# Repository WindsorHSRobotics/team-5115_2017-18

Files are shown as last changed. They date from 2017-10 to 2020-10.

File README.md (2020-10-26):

# Team-5115 (2017-18)
## Message from the repository creator, the Great, Anthony Romero: "This is the team 5115 2017 repository...don't break it!"

This repository is the result of the hard work of one of the greatest WHS robotics teams.  The members of this team were Anthony Romero, Dominic Scolari, Gavin Parrot and Liam McFadden.  Were it not for the failure to test the "claw systen" more thoroughly towards the end, they could have gone all the way (Let that be a lesson to all - fail to test at your own peril!).  Their repository includes an innovative omni wheel drive system using trigonometry which has resulted in a smoother, more responsive drive control all around.  Their innovative part designs should serve as an inspiration to all who view them.  Great work gentlemen, you will be immortalized here on GitHub.



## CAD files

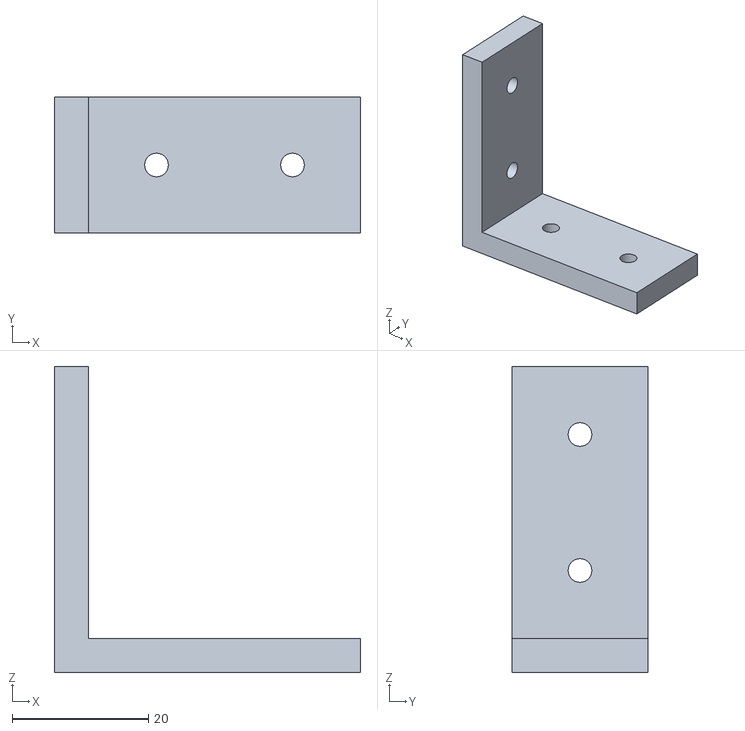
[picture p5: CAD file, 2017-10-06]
prints/8020 brackets/stl files/90 degree corner bracket.stl
45.0 x 20.0 x 45.0

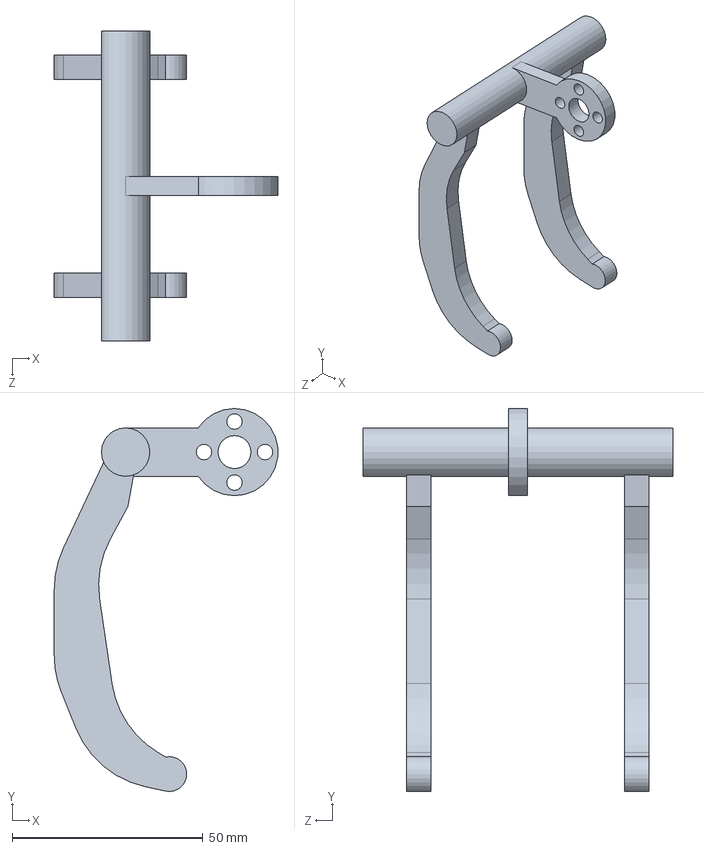
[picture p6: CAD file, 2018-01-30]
prints/adapters/sketchup of fusion files/clawmk2.SLDPRT
58.6 x 100.4 x 81.3 mm

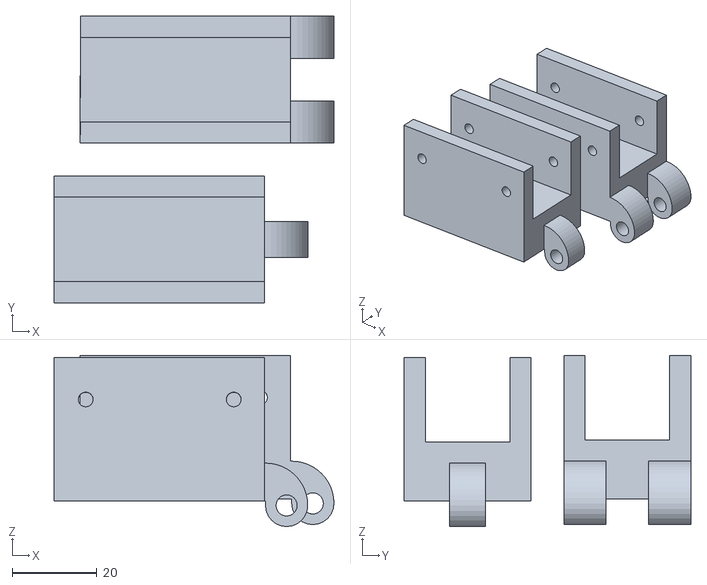
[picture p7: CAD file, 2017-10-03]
prints/connectors/hinges/sti files/Hinge a gavin1.stl
66.2 x 67.8 x 40.5

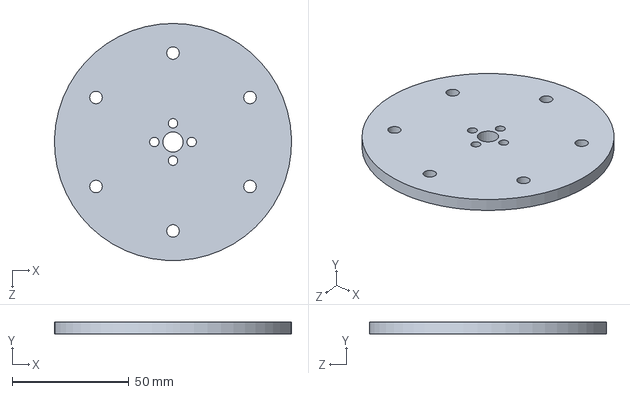
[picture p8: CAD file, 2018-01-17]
prints/gears/pinion roller mk1.SLDPRT
101.6 x 5.08 x 101.6 mm

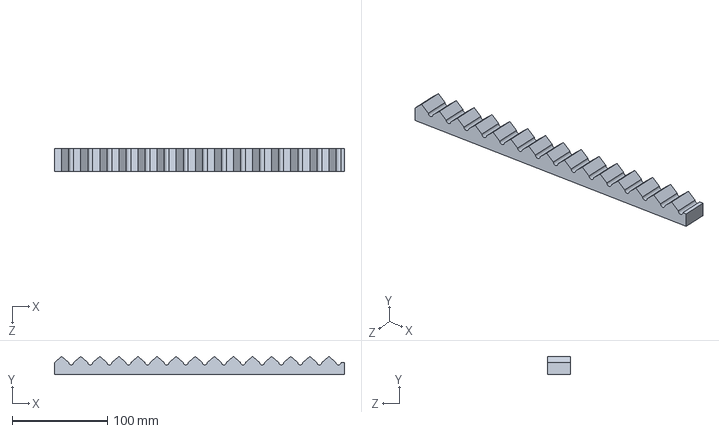
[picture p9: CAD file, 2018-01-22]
prints/gears/soldworks or fussion files/pinion rack mk2.SLDPRT
304.8 x 19.0 x 24.1 mm

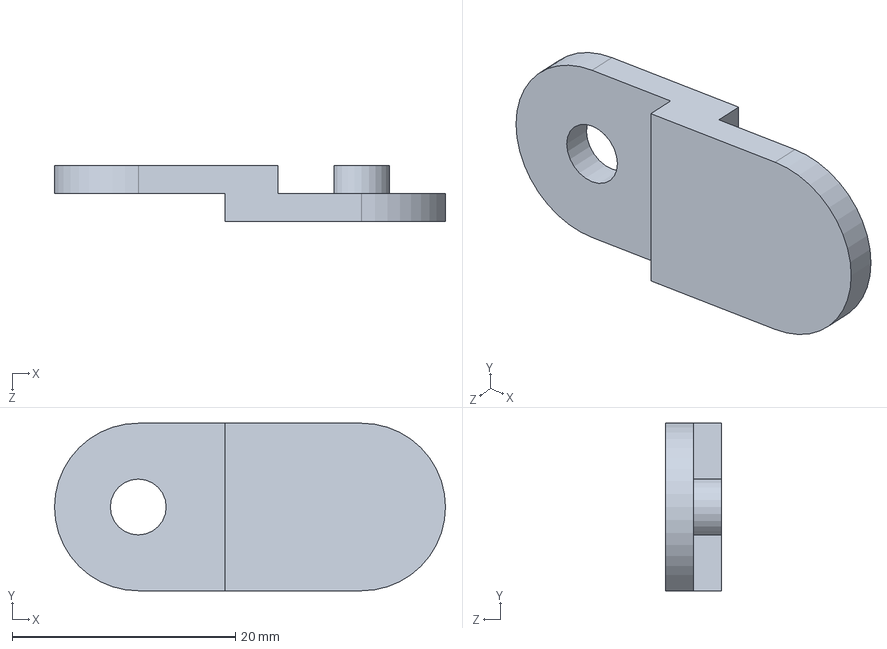
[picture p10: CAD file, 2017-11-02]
prints/wire protect track/leftmk1.SLDPRT
35.0 x 15.0 x 5.00 mm

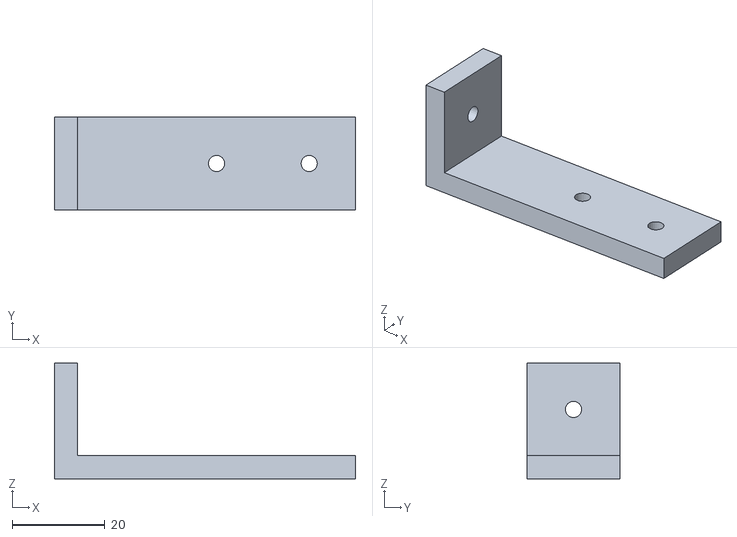
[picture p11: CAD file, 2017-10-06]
prints/8020 brackets/stl files/90 degree single anchor.stl
65.0 x 20.0 x 25.0

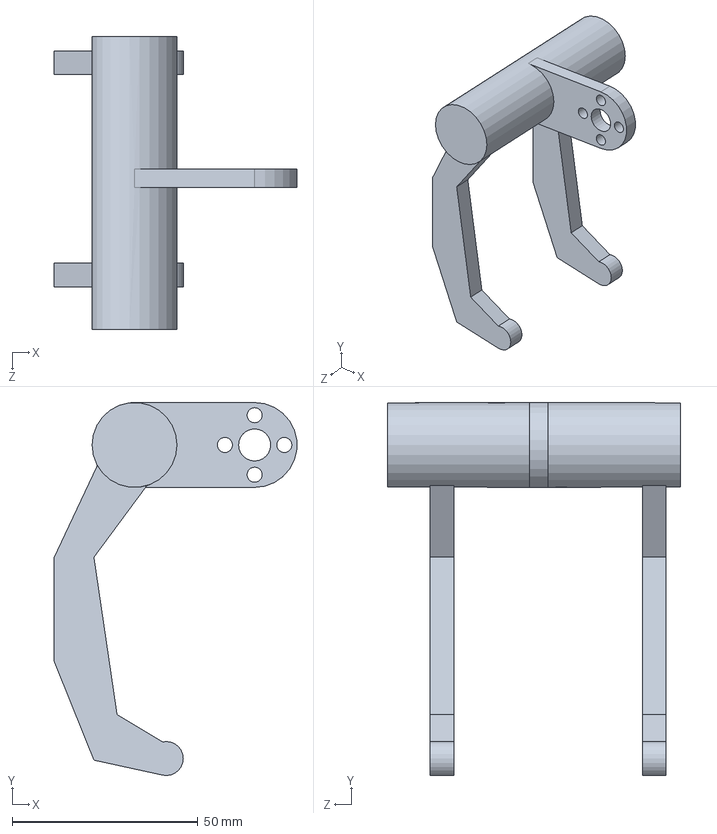
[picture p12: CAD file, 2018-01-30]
prints/adapters/sketchup of fusion files/clawmk3.SLDPRT
65.3 x 100.4 x 78.7 mm

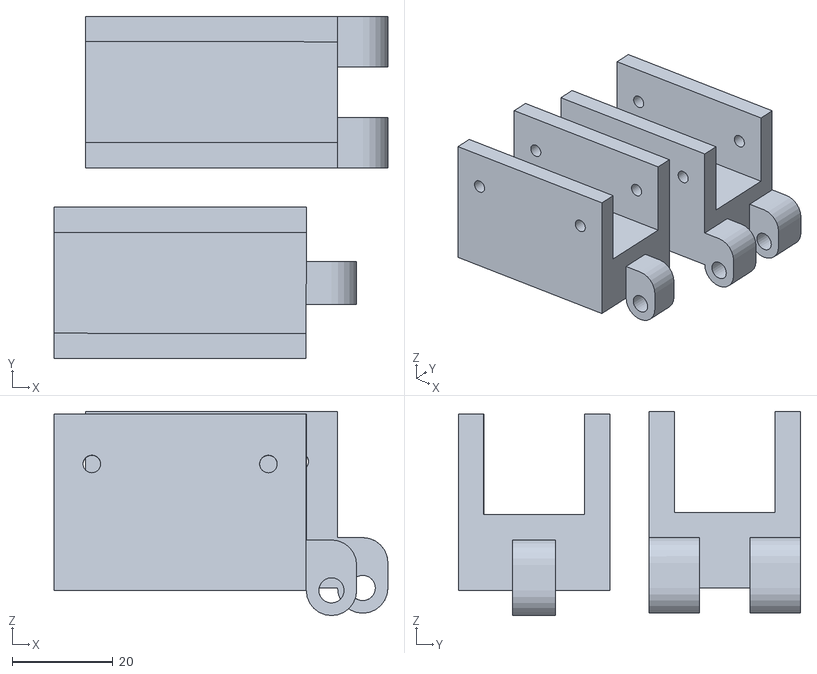
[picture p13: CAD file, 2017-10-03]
prints/connectors/hinges/sti files/hinge a gavin.stl
66.2 x 67.8 x 40.5

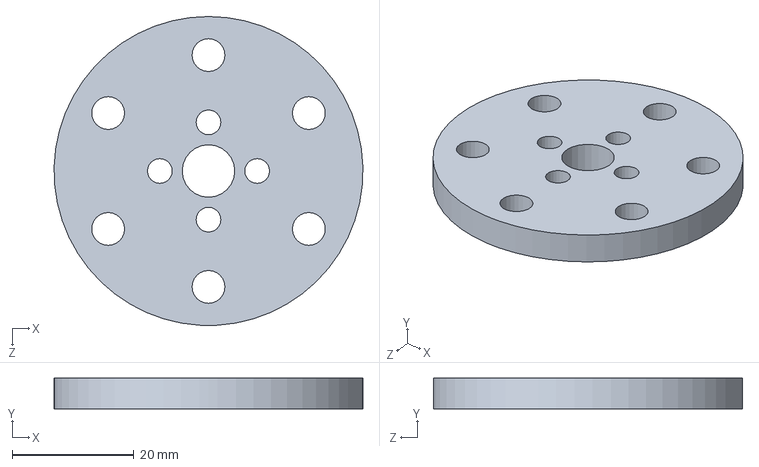
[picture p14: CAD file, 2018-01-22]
prints/gears/soldworks or fussion files/pinion roller mk2.SLDPRT
50.8 x 5.08 x 50.8 mm

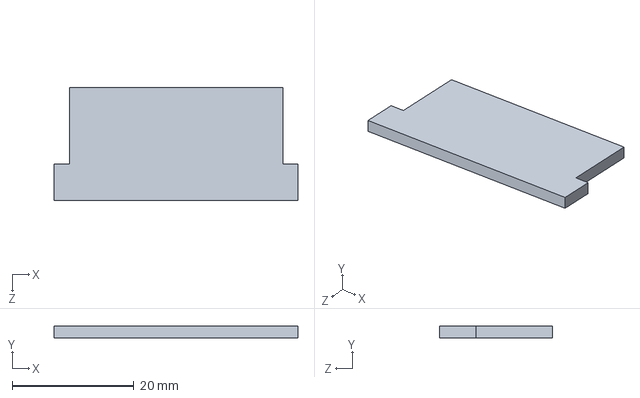
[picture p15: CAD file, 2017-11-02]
prints/wire protect track/tope wire protect track.SLDPRT
40.0 x 2.00 x 18.5 mm

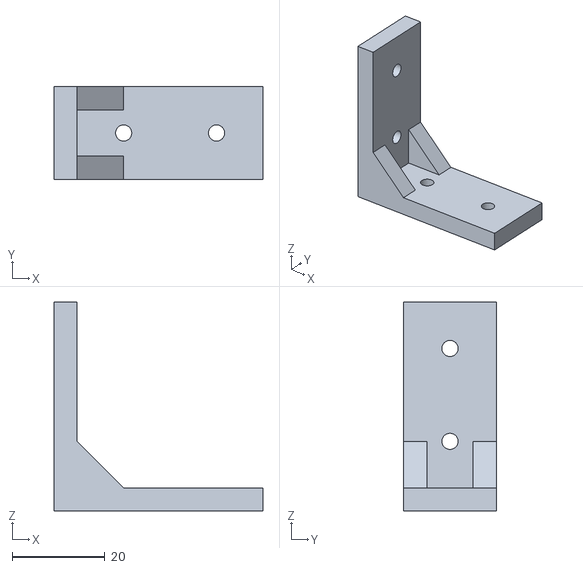
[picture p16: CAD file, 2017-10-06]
prints/8020 brackets/stl files/90 degree corner bracket with angle support.stl
45.0 x 20.0 x 45.0

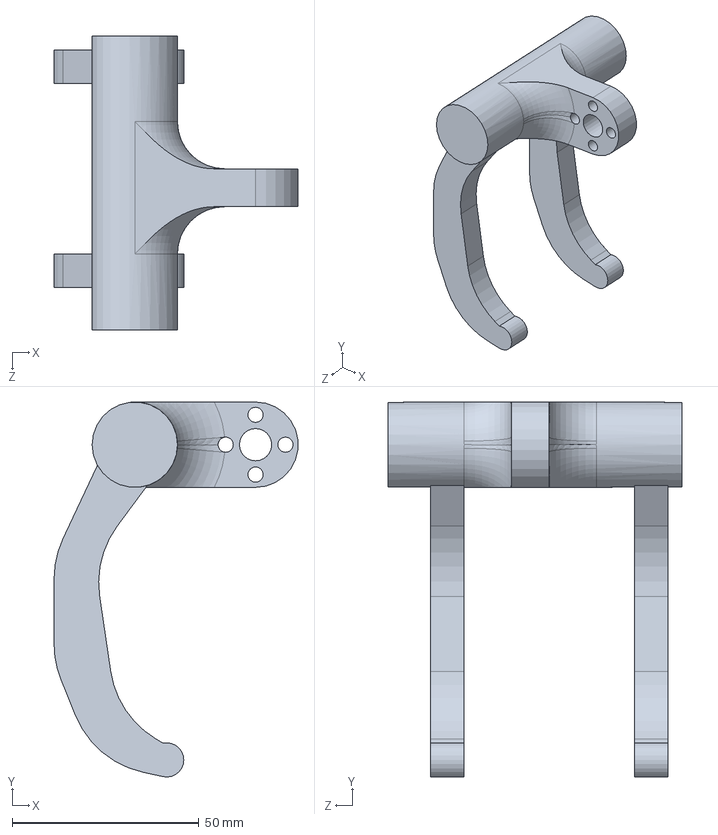
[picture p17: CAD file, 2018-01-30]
prints/adapters/sketchup of fusion files/clawmk4.SLDPRT
65.3 x 100.4 x 78.7 mm

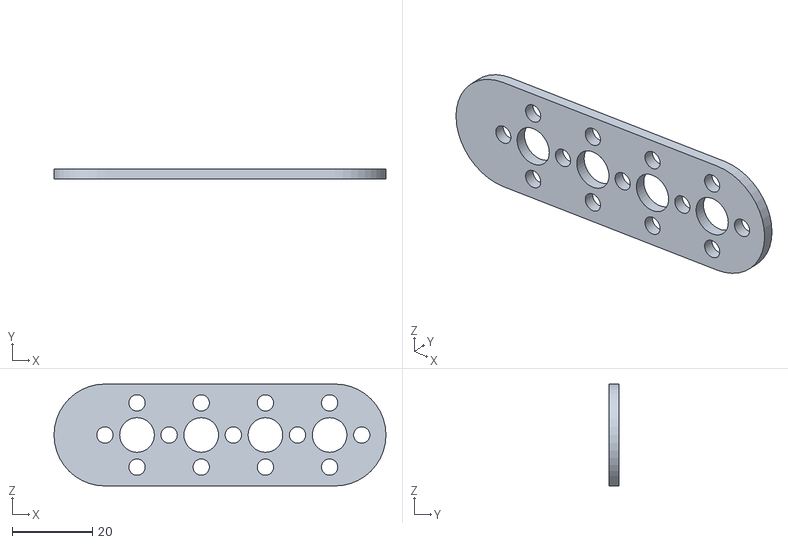
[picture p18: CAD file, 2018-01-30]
prints/adapters/stl files/phone mount platform.STL
82.8 x 2.54 x 25.4

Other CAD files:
prints/adapters/stl files/clawmk2.SLDPRT
prints/gears/stl files/pinion rack mk2.STL
prints/adapters/stl files/clawmk3.SLDPRT
prints/gears/stl files/pinion roller mk2.STL
prints/8020 brackets/sketchup or fusion files/90 degree 3 way corner bracket.skp
prints/8020 brackets/sketchup or fusion files/90 degree corner bracket with angle support.skp
prints/8020 brackets/sketchup or fusion files/90 degree corner bracket.skp
prints/8020 brackets/sketchup or fusion files/90 degree joining plane.skp
prints/8020 brackets/sketchup or fusion files/90 degree single anchor.skp
prints/8020 brackets/sketchup or fusion files/t joining plate.skp
prints/8020 brackets/stl files/90 degree 3 way corner bracket.stl
prints/8020 brackets/stl files/90 degree joining plane.stl
prints/8020 brackets/stl files/t joining plate.stl
prints/adapters/sketchup of fusion files/4in mechanum adapter.SLDPRT
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

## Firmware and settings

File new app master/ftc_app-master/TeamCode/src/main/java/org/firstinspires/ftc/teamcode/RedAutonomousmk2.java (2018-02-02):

package org.firstinspires.ftc.teamcode;
import com.qualcomm.robotcore.eventloop.opmode.Autonomous;
import com.qualcomm.robotcore.eventloop.opmode.Disabled;
import com.qualcomm.robotcore.eventloop.opmode.OpMode;
import com.qualcomm.robotcore.eventloop.opmode.TeleOp;
import com.qualcomm.robotcore.hardware.ColorSensor;
import com.qualcomm.robotcore.hardware.DcMotor;
import com.qualcomm.robotcore.hardware.DcMotorSimple;

import com.qualcomm.robotcore.hardware.Servo;
import com.qualcomm.robotcore.util.ElapsedTime;
import com.qualcomm.robotcore.util.Range;
import com.qualcomm.ftccommon.ClassManagerFactory;
import com.qualcomm.robotcore.hardware.CRServo;
import java.math.*;
import com.qualcomm.robotcore.eventloop.opmode.LinearOpMode;
import com.qualcomm.robotcore.hardware.DeviceInterfaceModule;
import com.qualcomm.robotcore.hardware.DigitalChannel;
import android.app.Activity;
import android.graphics.Color;
import android.view.View;

import org.firstinspires.ftc.robotcore.external.ClassFactory;
import org.firstinspires.ftc.robotcore.external.matrices.OpenGLMatrix;
import org.firstinspires.ftc.robotcore.external.navigation.RelicRecoveryVuMark;
import org.firstinspires.ftc.robotcore.external.navigation.VuforiaLocalizer;
import org.firstinspires.ftc.robotcore.external.navigation.VuforiaTrackable;
import org.firstinspires.ftc.robotcore.external.navigation.VuforiaTrackables;

/**
 * Created by romer on 2/2/2018.
 */
@Autonomous(name = "redautonomousmk2", group = "autonomous")
public class RedAutonomousmk2 extends LinearOpMode {
    public static final String TAG = "Vuforia VuMark Sample";
    OpenGLMatrix lastLocation = null;
    VuforiaLocalizer vuforia;


    private DcMotor F1 = null;
    private DcMotor F2 = null;
    private DcMotor R1 = null;
    private DcMotor R2 = null;
    //private DcMotor Winch = null;
    private CRServo claw_rotate = null;
    private DcMotor arm_rotate = null;
    private DcMotor extend = null;
    private DcMotor arm_rotate2;

    private Servo claw_front_left = null;
    private Servo claw_front_right = null;
    private Servo claw_rear_left = null;
    private Servo claw_rear_right = null;

    public ColorSensor color_sensor_front = null;
    @Override
    public void runOpMode(){
        //Initialize Vuforia
        int cameraMonitorViewId = hardwareMap.appContext.getResources().getIdentifier("cameraMonitorViewId", "id", hardwareMap.appContext.getPackageName());
        VuforiaLocalizer.Parameters parameters = new VuforiaLocalizer.Parameters(cameraMonitorViewId);
        parameters.vuforiaLicenseKey = "Aejo+Mn/////AAAAmYNCqjLr6Uddg42ubg+VizqJNbtrK1Kt0bA39uknxmHOwtAspXh3VmGQffi7LjZ4vshTH2jU+q0HDkzlWLa7mVdKrOxOhZS7SA4by5JBrGNlcOoIeE7xQjLZSIRVJb3mKWoijXBWAvi9E261Mm0eCtk45eLhoknnYRlFhJNqAJgHyIHZsaQ2OJYTpP0e4cMRCYpiYKUr0ceEA/sb/aulvf9tpvHMyO2cWXS4MtJLP6nEmjc4JX6F2vXtabQZuSi1cVLLqjf+395Z2pqkjYAMHRYg+s2+sd4y+3wglEKEI2ZeFajmP60WuIFBY5rb583ywQdJqjHgjl2yK4egY2I6Yr0KB2PElwduB383oTJR535A";
        parameters.cameraDirection = VuforiaLocalizer.CameraDirection.BACK;
        this.vuforia = ClassFactory.createVuforiaLocalizer(parameters);
        VuforiaTrackables relicTrackables = this.vuforia.loadTrackablesFromAsset("RelicVuMark");
        VuforiaTrackable relicTemplate = relicTrackables.get(0);
        relicTemplate.setName("relicVuMarkTemplate"); // can help in debugging; otherwise not necessary

        telemetry.addData(">", "Press Play to start");
        telemetry.update();

        relicTrackables.activate();

        telemetry.addData("Status", "Initialized");

        //Initialize hardware components
        F1 = hardwareMap.get(DcMotor.class, "F1");
        F2 = hardwareMap.get(DcMotor.class, "F2");
        R1 = hardwareMap.get(DcMotor.class, "R1");
        R2 = hardwareMap.get(DcMotor.class, "R2");
        arm_rotate2 = hardwareMap.get(DcMotor.class, "arm_rotate2");
        arm_rotate = hardwareMap.get(DcMotor.class,"arm_rotate");
        claw_rotate = hardwareMap.get(CRServo.class,"claw_rotate");
        extend = hardwareMap.get(DcMotor.class,"extend");
        color_sensor_front = hardwareMap.get(ColorSensor.class,"color_sensor_front");

        claw_front_left = hardwareMap.get(Servo.class, "claw_front_left");
        claw_front_right = hardwareMap.get(Servo.class,"claw_front_right");

        claw_rear_left = hardwareMap.get(Servo.class,"claw_rear_left");
        claw_rear_right = hardwareMap.get(Servo.class,"claw_rear_right");

        claw_front_right.setPosition(0);//grab the block
        claw_front_left.setPosition(.3);

        F1.setDirection(DcMotorSimple.Direction.FORWARD);
        F2.setDirection(DcMotorSimple.Direction.FORWARD);
        R1.setDirection(DcMotorSimple.Direction.FORWARD);
        R2.setDirection(DcMotorSimple.Direction.FORWARD);

        F1.setMode(DcMotor.RunMode.RUN_USING_ENCODER);
        F2.setMode(DcMotor.RunMode.RUN_USING_ENCODER);
        R1.setMode(DcMotor.RunMode.RUN_USING_ENCODER);
        R2.setMode(DcMotor.RunMode.RUN_USING_ENCODER);
        arm_rotate.setMode(DcMotor.RunMode.RUN_USING_ENCODER);



        waitForStart();

        F1.setPower(.125); //strafe left
        F2.setPower(.125);
        R1.setPower(-.125);
        R2.setPower(-.125);
        sleep(500);
        F1.setPower(0);
        F2.setPower(0);
        R1.setPower(0);
        R2.setPower(0);



        arm_rotate.setPower(.2); //raise arm to get clear of camera and wall
        arm_rotate2.setPower(.2);
        sleep(1000);
        arm_rotate2.setPower(0);
        arm_rotate.setPower(0);

        extend.setPower(-.25); //extend drawer slides (with color sensor)
        sleep(1500);
        extend.setPower(0);

        sleep(1000);

        if(color_sensor_front.red() < color_sensor_front.blue()){ //if red is on left

            telemetry.addData("color = ","red");
            telemetry.update();

            F1.setPower(-.125);//turns left
            F2.setPower(-.125);
            R1.setPower(-.125);
            R2.setPower(-.125);
            sleep(200);
            F1.setPower(0);
            F2.setPower(0);
            R1.setPower(0);
            R2.setPower(0);

            extend.setPower(.25);//retract slide
            sleep(1700);
            extend.setPower(0);

            F1.setPower(.125);//rotate back
            F2.setPower(.125);
            R1.setPower(.125);
            R2.setPower(.125);
            sleep(200);
            F1.setPower(0);
            F2.setPower(0);
            R1.setPower(0);
            R2.setPower(0);

        }
        else if(color_sensor_front.red() > color_sensor_front.blue()){ //if red is on right

            telemetry.addData("color = ","blue");
            telemetry.update();

            F1.setPower(.125); //turns right
            F2.setPower(.125);
            R1.setPower(.125);
            R2.setPower(.125);
            sleep(200);
            F1.setPower(0);
            F2.setPower(0);
            R1.setPower(0);
            R2.setPower(0);

            extend.setPower(.25); //retract the slides
            sleep(1700);
            extend.setPower(0);

            F1.setPower(-.125); //rotate back
            F2.setPower(-.125);
            R1.setPower(-.125);
            R2.setPower(-.125);
            sleep(200);
            F1.setPower(0);
            F2.setPower(0);
            R1.setPower(0);
            R2.setPower(0);

        }
        else{ //nothing detected; give up and move on
            telemetry.addData("color = ", "undetected");
            extend.setPower(.25); //retract the slides
            sleep(1700);
            extend.setPower(0);
        }

        sleep(1000);

        int lrc; //new variable for horizontal movement

        RelicRecoveryVuMark vuMark = RelicRecoveryVuMark.from(relicTemplate); //read the page

        if(vuMark == RelicRecoveryVuMark.LEFT) lrc = 3700; //aim for the left column
        else if(vuMark == RelicRecoveryVuMark.CENTER) lrc = 3220; //aim for the middle column
        else if(vuMark == RelicRecoveryVuMark.RIGHT) lrc = 2700; //aim for the right column
        else lrc = 2520; //if none detected, default to center

        telemetry.addData("VuMark", "%s visible", vuMark);
        telemetry.update();
        sleep(1000);

        F1.setPower(-.125); //strafe left to correct column
        F2.setPower(-.125);
        R1.setPower(.125);
        R2.setPower(.125);
        sleep(lrc);
        F1.setPower(0);
        F2.setPower(0);
        R1.setPower(0);
        R2.setPower(0);

        claw_rotate.setPower(.1); //rotate the claw table
        sleep(350);
        claw_rotate.setPower(0);

        sleep(500);

        F1.setPower(-.25); //reverse
        F2.setPower(.25);
        R1.setPower(-.25);
        R2.setPower(.25);
        sleep(500);
        F1.setPower(0);
        F2.setPower(0);
        R1.setPower(0);
        R2.setPower(0);

        sleep(300);

        claw_rotate.setPower(.3); //rotate the claw table (again)
        sleep(750);
        claw_rotate.setPower(0);

        arm_rotate.setPower(-.1);//lower the arm (in two motions)
        arm_rotate2.setPower(-.1);
        sleep(300);
        arm_rotate2.setPower(0);
        arm_rotate.setPower(0);
        sleep(300);
        arm_rotate.setPower(-.1);
        arm_rotate2.setPower(-.1);
        sleep(300);
        arm_rotate2.setPower(0);
        arm_rotate.setPower(0);

        F1.setPower(.125); //drive forward to score
        F2.setPower(-.125);
        R1.setPower(.125);
        R2.setPower(-.125);
        sleep(1400);
        F1.setPower(0);
        F2.setPower(0);
        R1.setPower(0);
        R2.setPower(0);

        sleep(250);

        claw_front_left.setPosition(0); //open claws; drop block
        claw_front_right.setPosition(35);

        F1.setPower(-.25); //reverse
        F2.setPower(.25);
        R1.setPower(-.25);
        sleep(400);
    }

}

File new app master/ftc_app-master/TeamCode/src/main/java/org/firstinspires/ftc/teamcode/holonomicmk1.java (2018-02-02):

/* Copyright (c) 2017 FIRST. All rights reserved.
 *
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
 * Neither the name of FIRST nor the names of its contributors may be used to endorse or
 * promote products derived from this software without specific prior written permission.
 *
 * NO EXPRESS OR IMPLIED LICENSES TO ANY PARTY'S PATENT RIGHTS ARE GRANTED BY THIS
 * LICENSE. THIS SOFTWARE IS PROVIDED BY THE COPYRIGHT HOLDERS AND CONTRIBUTORS
 * "AS IS" AND ANY EXPRESS OR IMPLIED WARRANTIES, INCLUDING, BUT NOT LIMITED TO,
 * THE IMPLIED WARRANTIES OF MERCHANTABILITY AND FITNESS FOR A PARTICULAR PURPOSE
 * ARE DISCLAIMED. IN NO EVENT SHALL THE COPYRIGHT OWNER OR CONTRIBUTORS BE LIABLE
 * FOR ANY DIRECT, INDIRECT, INCIDENTAL, SPECIAL, EXEMPLARY, OR CONSEQUENTIAL
 * DAMAGES (INCLUDING, BUT NOT LIMITED TO, PROCUREMENT OF SUBSTITUTE GOODS OR
 * SERVICES; LOSS OF USE, DATA, OR PROFITS; OR BUSINESS INTERRUPTION) HOWEVER
 * CAUSED AND ON ANY THEORY OF LIABILITY, WHETHER IN CONTRACT, STRICT LIABILITY,
 * OR TORT (INCLUDING NEGLIGENCE OR OTHERWISE) ARISING IN ANY WAY OUT OF THE USE
 * OF THIS SOFTWARE, EVEN IF ADVISED OF THE POSSIBILITY OF SUCH DAMAGE.
 */

package org.firstinspires.ftc.teamcode;

import com.qualcomm.robotcore.eventloop.opmode.Disabled;
import com.qualcomm.robotcore.eventloop.opmode.OpMode;
import com.qualcomm.robotcore.eventloop.opmode.TeleOp;
import com.qualcomm.robotcore.hardware.DcMotor;
import com.qualcomm.robotcore.hardware.DcMotorSimple;

import com.qualcomm.robotcore.hardware.Servo;
import com.qualcomm.robotcore.util.ElapsedTime;
import com.qualcomm.robotcore.util.Hardware;
import com.qualcomm.robotcore.util.Range;
import com.qualcomm.ftccommon.ClassManagerFactory;
import com.qualcomm.robotcore.hardware.CRServo;
import java.math.*;
import com.qualcomm.robotcore.hardware.ColorSensor;




@TeleOp(name="holonomicmk1", group="teliop")

public class holonomicmk1 extends OpMode
{
    // Declare OpMode members.
    private ElapsedTime runtime = new ElapsedTime();
    private DcMotor F1 = null;
    private DcMotor F2 = null;
    private DcMotor R1 = null;
    private DcMotor R2 = null;
    //private DcMotor Winch = null;
    private CRServo claw_rotate = null;
    private DcMotor arm_rotate = null;
    private DcMotor arm_rotate2 = null;
    private DcMotor extend = null;

    public Servo claw_front_left = null;
    public Servo claw_front_right = null;
    private Servo Color_Arm = null;
    private Servo claw_rear_left = null;
    private Servo claw_rear_right = null;


       /*
     * Code to run ONCE when the driver hits INIT
     */
    @Override
    public void init() {
        telemetry.addData("Status", "Initialized");

        F1 = hardwareMap.get(DcMotor.class, "F1");
        F2 = hardwareMap.get(DcMotor.class, "F2");
        R1 = hardwareMap.get(DcMotor.class, "R1");
        R2 = hardwareMap.get(DcMotor.class, "R2");
        arm_rotate2 = hardwareMap.get(DcMotor.class, "arm_rotate2");
        arm_rotate = hardwareMap.get(DcMotor.class,"arm_rotate");
        claw_rotate = hardwareMap.get(CRServo.class,"claw_rotate");
        extend = hardwareMap.get(DcMotor.class,"extend");

        claw_front_left = hardwareMap.get(Servo.class, "claw_front_left");
        claw_front_right = hardwareMap.get(Servo.class,"claw_front_right");
        Color_Arm = hardwareMap.get(Servo.class,"color_arm");
        claw_rear_left = hardwareMap.get(Servo.class,"claw_rear_left");
        claw_rear_right = hardwareMap.get(Servo.class,"claw_rear_right");


        F1.setDirection(DcMotorSimple.Direction.FORWARD);
        F2.setDirection(DcMotorSimple.Direction.FORWARD);
        R1.setDirection(DcMotorSimple.Direction.FORWARD);
        R2.setDirection(DcMotorSimple.Direction.FORWARD);

        //Winch.setDirection(DcMotorSimple.Direction.FORWARD);

        F1.setMode(DcMotor.RunMode.RUN_USING_ENCODER);
        F2.setMode(DcMotor.RunMode.RUN_USING_ENCODER);
        R1.setMode(DcMotor.RunMode.RUN_USING_ENCODER);
        R2.setMode(DcMotor.RunMode.RUN_USING_ENCODER);
        arm_rotate.setMode(DcMotor.RunMode.RUN_USING_ENCODER);




        // Initialize the hardware variables. Note that the strings used here as parameters
        // to 'get' must correspond to the names assigned during the robot configuration
        // step (using the FTC Robot Controller app on the phone).

        telemetry.addData("Status", "Initialized v1");
    }

    /*
     * Code to run REPEATEDLY after the driver hits INIT, but before they hit PLAY
     */
    @Override
    public void init_loop() {
        claw_front_right.setPosition(0);
        claw_front_left.setPosition(35);
        claw_rear_right.setPosition(0);
        claw_rear_left.setPosition(35);
        Color_Arm.setPosition(90);

    }

    /*
     * Code to run ONCE when the driver hits PLAY
     */
    @Override
    public void start() {
        runtime.reset();
    }

    /*
     * Code to run REPEATEDLY after the driver hits PLAY but before they hit STOP
     */
    @Override
    public void loop() {
        double leftstick_x_sqr;
        double leftstick_y_sqr;
        double power;
        double angle;

        double powerF1;
        double powerF2;
        double powerR1;
        double powerR2;
        double claw_open = 180;
        double claw_close = 80;
        Color_Arm.setPosition(.5);


        angle = Math.atan2(gamepad1.left_stick_x, gamepad1.left_stick_y);//finds angle of joystick
        telemetry.addData("angle: ", angle);//adds telemetry for troubleshooting code

        leftstick_x_sqr = gamepad1.left_stick_x * gamepad1.left_stick_x;
        leftstick_y_sqr = gamepad1.left_stick_y * gamepad1.left_stick_y;
        power = Math.sqrt(leftstick_x_sqr + leftstick_y_sqr);//finds relative power of joystick using pythagorean theorem
        telemetry.addData("power: ", power);

        double Pi = Math.PI/4;//to avoid having to type this everytime

        powerF2 = (power * Math.cos(angle - Pi)) + gamepad1.right_stick_x;
        powerF1 = (power * -Math.cos(angle + Pi)) + gamepad1.right_stick_x;//assigning each motor power based on calculated sin wave
        powerR1 = (power * -Math.cos(angle - Pi)) + gamepad1.right_stick_x;//right stick is used for y axis rotation
        powerR2 = (power * Math.cos(angle + Pi)) + gamepad1.right_stick_x;


        powerF1 = Range.clip(powerF1,-1.0, 1.0);//clips values to avoid program errors
        powerF2 = Range.clip(powerF2,-1.0, 1.0);
        powerR1 = Range.clip(powerR1,-1.0, 1.0);
        powerR2 = Range.clip(powerR2,-1.0, 1.0);

        telemetry.addData("right stick x: ", gamepad1.right_stick_x);

        if(power > .1 || Math.abs(gamepad1.right_stick_x)>.1){
            F1.setPower(powerF1);
            F2.setPower(powerF2);//applies motor power if joystick is moved
            R1.setPower(powerR1);
            R2.setPower(powerR2);
        }
        else{
            F1.setPower(0);
            F2.setPower(0);
            R1.setPower(0);//stops robot when no joystick is pressed 
            R2.setPower(0);
        }
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

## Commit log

2017-10-03 should be current as of 10/3 on lab computer
2017-10-03 these are the 3d print files stored on the lab computer
    [Hinge a gavin1.skp, Hinge a gavin1.stl, hinge 2 a.skp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]
2017-10-03 file for the adaptor for the mecanum wheels to motor axle mount
    [mecanum_axlehub_adapter.stl]
2017-10-03 the apk for the version of the driver station we use. version 1.5
2017-10-06 these are all the 3d files stored on my personal computer
    [90 degree 3 way corner bracket.skp, 90 degree 3 way corner bracket.stl, 90 degree corner bracket with angle support.skp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]
2017-10-09 added first draft for servo code
2017-10-11 liniar slide print
    [liniar slide.skp, liniar slide.stl]
2017-10-11 fixed to 5 mm width
    [liniar slide.skp, liniar slide.stl]
2017-10-16 new code for lift powered by triggers
2017-10-23 fixed servo code
2017-11-02 lots o stuff on the lab computer
    [4in mechanum adapter.SLDPRT, 4in mechanum adapter.STL, leftmk1.SLDPRT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]
2017-11-02 fixed hole size in wheel plate
    [4in mechanum adapter.SLDPRT]
2017-11-02 just fixed hole size in stl file
    [4in mechanum adapter.SLDPRT, 4in mechanum adapter.STL]
2017-11-02 files for wire tracks and drawer slide mechanism
    [drawerslidebottom.SLDPRT, drawerslidebottom.STL, drawerslidetop.SLDPRT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]
2017-11-03 fixed hole size and routing on the drawer slide bottom piece
    [drawerslidebottom.SLDPRT, drawerslidebottom.STL]
2017-11-06 hopefully fixed code for new wheel orrientation( x to square)
    [MecanumTest.java]
2017-11-07 back 2 wheels are working. dominics computer refuses to change program on phones for last 2 wheels
2017-11-10 fresh up to date app master v3.5
    [app_settings.xml]
2017-11-10 first draft of the existing opmode but on the new v3.5 software. no servo code included yet
2017-11-15 added claw code
2017-11-15 fixed the servo code. now with 3 toggles!!
    [holonomicmk1.java]
2017-11-18 fixed code. added lift arm motor plus claw rotate servo. done @ liberty commons fll qualifier
    [holonomicmk1.java]
2017-11-19 added code for claw servos
2017-11-21 latest 3d files
    [clawmk1.SLDPRT, clawmk1.STL, clawmk2.SLDPRT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]
2017-11-28 added code for winch and upped power of arm motor
2017-12-08 12/8 lab comp 3d parts files
    [GearPinion_4inCircumference.stl, Gear_Rack_4inCircumference_12inLength.stl, Gear_Rack_4inCircumference_2.222inLength.stl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]
2017-12-08 added triggers for extender, added arm encoder
2017-12-13 fixed endpoints for claw code to reduce grinding
    [holonomicmk1.java]
2017-12-13 first draft of red autonomous. code for color sensing is commented out as servo cannot be securely attached to
2017-12-14 color sensor test + autonomous has only 1 color sensor now
2017-12-14 added files from lab comp 12/14
    [GenevaDriveWheel10inmkl1.SLDPRT, GenevaWheel10inmk1.SLDPRT, brakemountmk1.SLDPRT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]
2017-12-19 added code for rear servos
2017-12-20 adeed first draft of brake addapter for the servos. also added constrant to 4in mechanum to make copying and pasting the holes for the hub mount easier
    [brake servo adapter mk1.SLDPRT, brake servo adapter mk1.STL]
2017-12-20 added folder for cnc mill files and frist draft of pannel for underisde of robot for electronics
2017-12-20 changed code for resting position of color arm servo
2017-12-21 core device interface strain releif
    [core device strain relief 1.SLDPRT, core device strain relief 1.STL]
2018-01-08 added code for variable power of lift motor and color bar
2018-01-09 new claw mk 5 to try to meet sizing
    [4in mechanum outside logo.SLDPRT, clawmk5.SLDPRT, clawmk5.STL]
2018-01-17 added files for dom's rollers
    [pin mk1.SLDPRT, pinion rack mk1.SLDPRT, pinion rack mk1.STL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]
2018-01-19 changed code for lift motor for name and extender motor on a 4th motor controler
2018-01-22 added files for doms gear rack
    [pinion rack mk1.SLDPRT, pinion rack mk2.STL, pinion roller mk1 v1.SLDPRT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]
2018-01-22 lab computer stuff
    [pinion rack mk1.SLDPRT, pinion rack mk2.SLDPRT, pinion rack mk2.STL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]
2018-01-26 added new phone mount beam to avoid drilling out real parts
    [phone mount platform.SLDPRT, phone mount platform.STL]
2018-01-30 fixed phone mount for space
    [4in mechanum adapter.SLDPRT, phone mount platform.SLDPRT, phone mount platform.STL]
2018-01-30 recovered old versions of claw
    [clawmk3.SLDPRT, clawmk4.SLDPRT]
2018-01-30 recovered all versions of claw
    [clawmk2.SLDPRT, clawmk2.STL, clawmk3.STL]
2018-02-02 fixed so claws don't open all the way to preserve servos
    [holonomicmk1.java]
2018-02-02 fixed red because it was a mirror of blue
    [RedAutonomousmk2.java]
